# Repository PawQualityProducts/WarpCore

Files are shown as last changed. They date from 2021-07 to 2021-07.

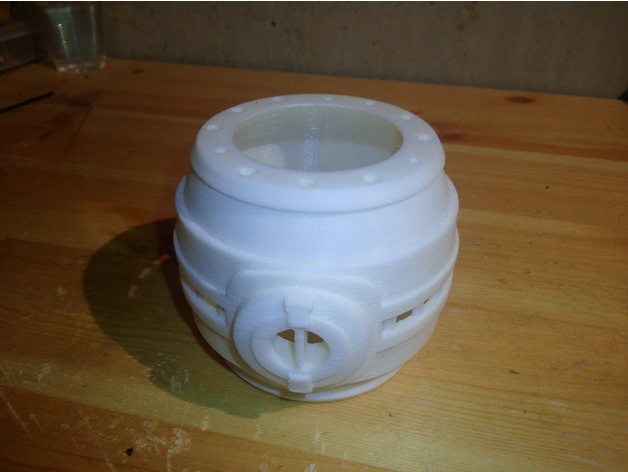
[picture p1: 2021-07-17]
images/a623d3ce466ae3677e4435cb19036652_preview_featured.JPG

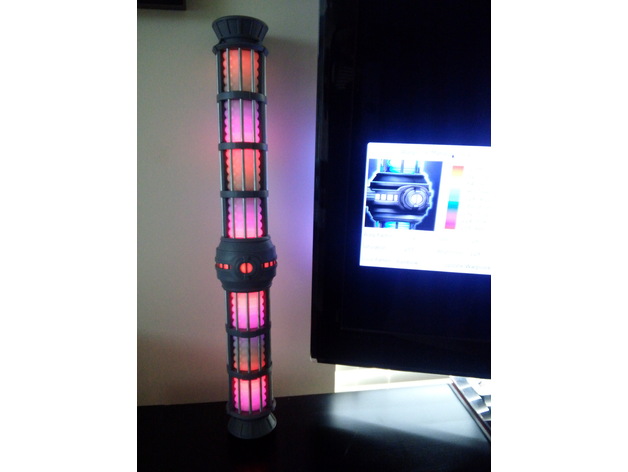
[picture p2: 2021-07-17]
images/a03e35211922563c592e2617a49f9ae8_preview_featured.JPG

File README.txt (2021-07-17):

                   .:                     :,                                          
,:::::::: ::`      :::                   :::                                          
,:::::::: ::`      :::                   :::                                          
.,,:::,,, ::`.:,   ... .. .:,     .:. ..`... ..`   ..   .:,    .. ::  .::,     .:,`   
   ,::    :::::::  ::, :::::::  `:::::::.,:: :::  ::: .::::::  ::::: ::::::  .::::::  
   ,::    :::::::: ::, :::::::: ::::::::.,:: :::  ::: :::,:::, ::::: ::::::, :::::::: 
   ,::    :::  ::: ::, :::  :::`::.  :::.,::  ::,`::`:::   ::: :::  `::,`   :::   ::: 
   ,::    ::.  ::: ::, ::`  :::.::    ::.,::  :::::: ::::::::: ::`   :::::: ::::::::: 
   ,::    ::.  ::: ::, ::`  :::.::    ::.,::  .::::: ::::::::: ::`    ::::::::::::::: 
   ,::    ::.  ::: ::, ::`  ::: ::: `:::.,::   ::::  :::`  ,,, ::`  .::  :::.::.  ,,, 
   ,::    ::.  ::: ::, ::`  ::: ::::::::.,::   ::::   :::::::` ::`   ::::::: :::::::. 
   ,::    ::.  ::: ::, ::`  :::  :::::::`,::    ::.    :::::`  ::`   ::::::   :::::.  
                                ::,  ,::                               ``             
                                ::::::::                                              
                                 ::::::                                               
                                  `,,`

https://www.thingiverse.com/thing:2008591
1701-D Warp Core (HI-RESOLUTION) by Novel_Mutations is licensed under the Creative Commons - Attribution - Non-Commercial license.
http://creativecommons.org/licenses/by-nc/3.0/

# Summary

I can't believe I hadn't seen ThePlanetMike's Warp Core Lamp or any of the others that followed before this week. I immediately downloaded it to start printing but I didn't feel it was up to star feet standards. I quickly brought it in to utopia planitia for a refit and this is what we ended up with.

It is 73% of the originals size but has the same power output. The resolution has been increased by a factor of at least three times and to the point that the facets are no longer visible. All parts now fit on a 100mm x 100mm bed.

In addition to increasing the resolution I have done the following:

The thin round posts are no longer printed. They are now replaced with 5mm diameter steel bars (metal braces I had lying around from the back of Ikea shelving units (now called HEJNE)). You could also use stainless steel automotive brake line tubing.

The ribbed "Vertical Tension Members" are now printed on their sides for a better finish and easier printing. They have a hole down the center for a piece of metal coat hanger wire as a support and to keep them all in line.

The "Magnetic Constrictor Lens" has been remodelled to be a solid which you only print the one perimeter, no infill and no top or bottom layers.

The lens inside the "Warp Reaction Chamber" is now one solid piece that you only print one perimeter, no infill and no top or bottom layers.

The "Phase Adjustment Coils" have been remodelled entirely without the round posts or the vertical tension members.

The "Reactant Injectors" have been entirely remodelled to have no intersecting faces.

The "Warp Reaction Chamber" has had some remodelling on the interior to use less plastic.

The Lamp base has been remodelled to be high resolution. I has a wire hole at the back for the power cord.

The only part that requires support is the "Warp Reaction Chamber".

The entire thing prints very quickly especially the single wall lens's.

UPDATE: May 17, 2018
Android program to control warpcore submitted by user Catmandu13 and is available on the google play store for free at https://play.google.com/store/apps/details?id=appinventor.ai_cterry42.WarpController2

UPDATE: Jan 2, 2017 : Added "Lamp Base.stl" to allow it to be used as a table lamp like the original one was intended. I also updated the Blend file with the new base.

UPDATE: Feb 6, 2017: Created http://www.thingiverse.com/thing:2090708 which is the light diffuser I used inside the model.

https://theledroom.wordpress.com/2017/02/13/ncc-1701-d-warp-core/

# Print Settings

Printer: Tantillus
Rafts: No
Supports: Yes
Resolution: 0.15

Notes: 
Print the Warp Reaction Chamber using support is recommended.

The Lens's should be printed using a single perimeter, zero infill and no top or bottom layers. Spiral mode if its an option.

# Post-Printing

Minimum printed parts:
1 - Reaction Chamber
1 - Reaction Chamber Lens
2 - Magnetic Constrictor Lens's
6 - Vertical Tension Members
2 - Reactant Injectors (or 1 - Reactant Injector and 1 - Lamp Base)
0 - Phase Adjustment Coils

For each additional section added you will need the following:
1 - Phase Adjustment Coil
1 - Magnetic Constrictor Lens
3 - Vertical Tension Members

# How I Designed This

To increase the resolution of the original parts I imported them into Blender and marked the sharp edges and then set the multi-resolution modifier to work. They are not applied in the Blend file so you can go in and adjust the resolution to your liking.

The parts that I completely remodelled are also done the same way but start off at a higher resolution. 

# Videos

<iframe src="//player.vimeo.com/video/202879164" frameborder="0" webkitallowfullscreen mozallowfullscreen allowfullscreen></iframe>
Running at Warp factor 2

<iframe src="//player.vimeo.com/video/202879163" frameborder="0" webkitallowfullscreen mozallowfullscreen allowfullscreen></iframe>
Running in rainbow mode

<iframe src="//player.vimeo.com/video/202879160" frameborder="0" webkitallowfullscreen mozallowfullscreen allowfullscreen></iframe>
Part of a Warp Core breach cycle

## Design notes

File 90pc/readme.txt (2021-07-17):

Components printed at 90% normal size allows for 4 restrictor lenses to be printed top and bottom

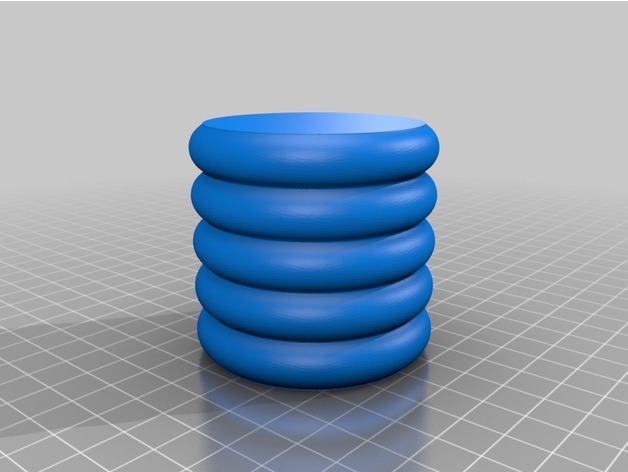
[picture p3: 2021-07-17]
images/d6bcbce92533f9e681ca99b0f44db99e_preview_featured.jpg

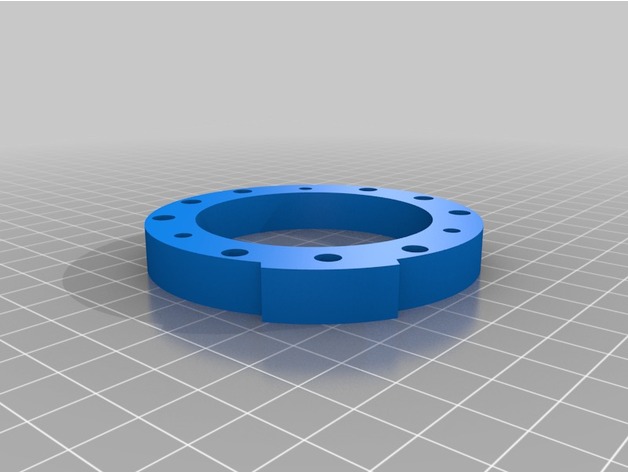
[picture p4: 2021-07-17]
images/adf16bbb0086b629d89b5c633a125ff6_preview_featured.jpg

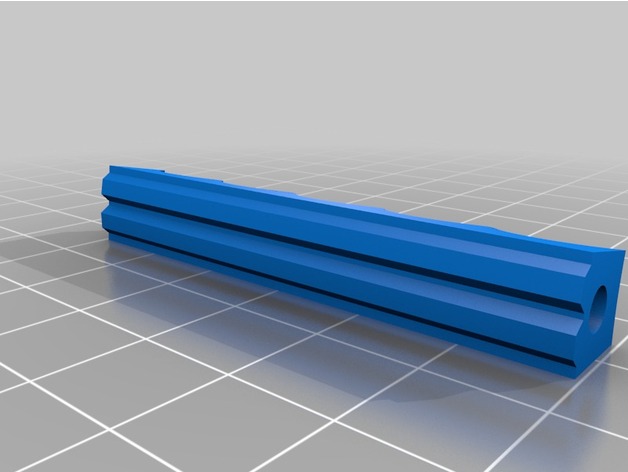
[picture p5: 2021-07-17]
images/73b58e25b4730450576f030052adf6e0_preview_featured.jpg

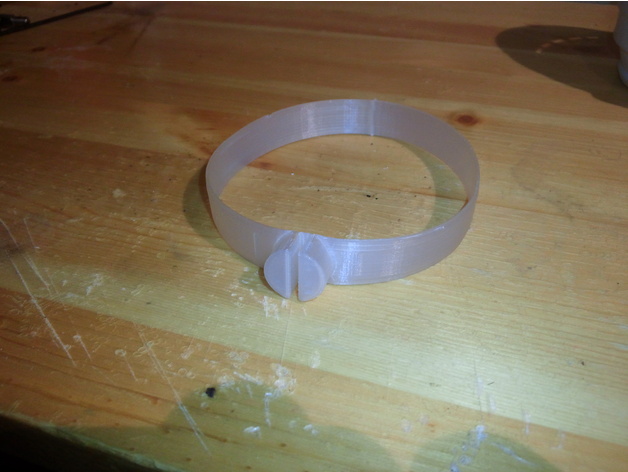
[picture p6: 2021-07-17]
images/f1cb4d1bf836be61b849b8668d147068_preview_featured.JPG

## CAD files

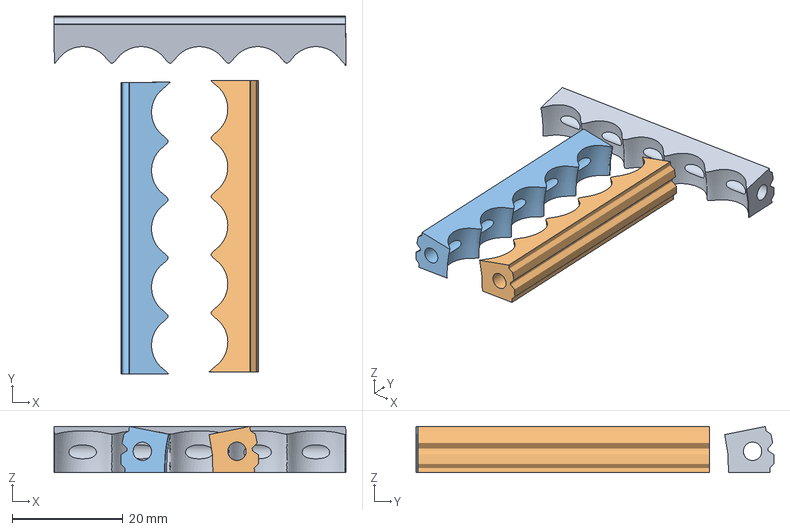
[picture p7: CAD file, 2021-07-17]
90pc/Cura/Vertical_Tension_Member_90pc.3mf
52.6 x 64.6 x 8.33 mm
Vertical_Tension_Member.stl
Vertical_Tension_Member.stl(1)
Vertical_Tension_Member.stl(2)

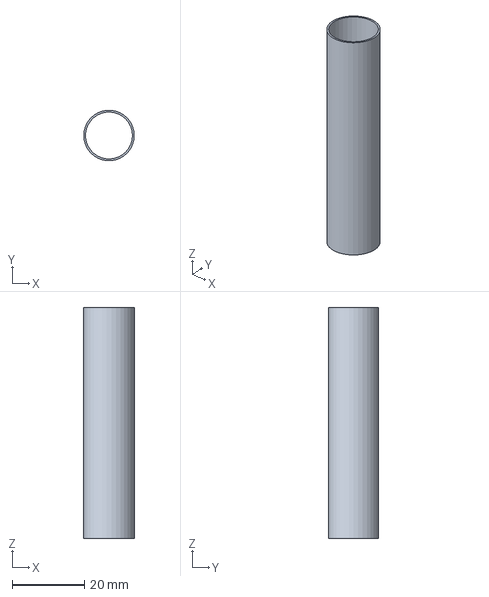
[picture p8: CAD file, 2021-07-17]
Cura/CE5P_diffuser_reactor.3mf
14.0 x 13.9 x 64.0 mm

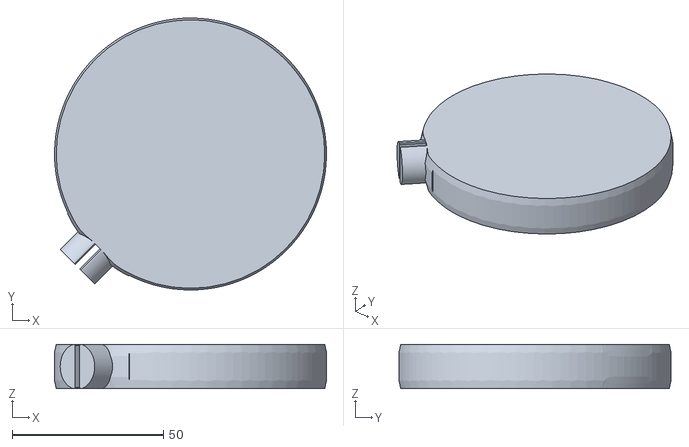
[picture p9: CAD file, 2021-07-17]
files/Warp_Reaction_Chamber_Lens.stl
89.8 x 89.8 x 14.6

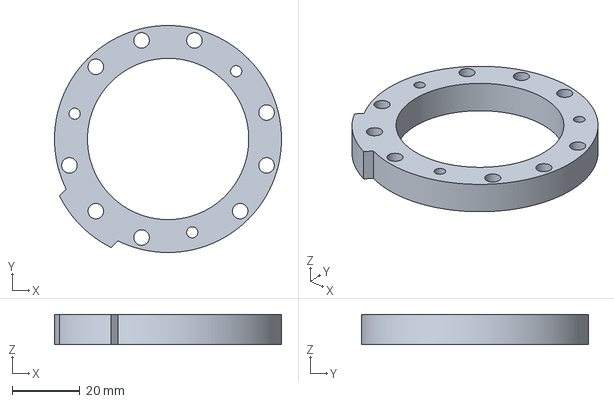
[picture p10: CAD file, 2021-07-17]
90pc/Cura/CE5P_Phase_Adjustment_Coil_90pc.3mf
67.3 x 67.3 x 9.00 mm

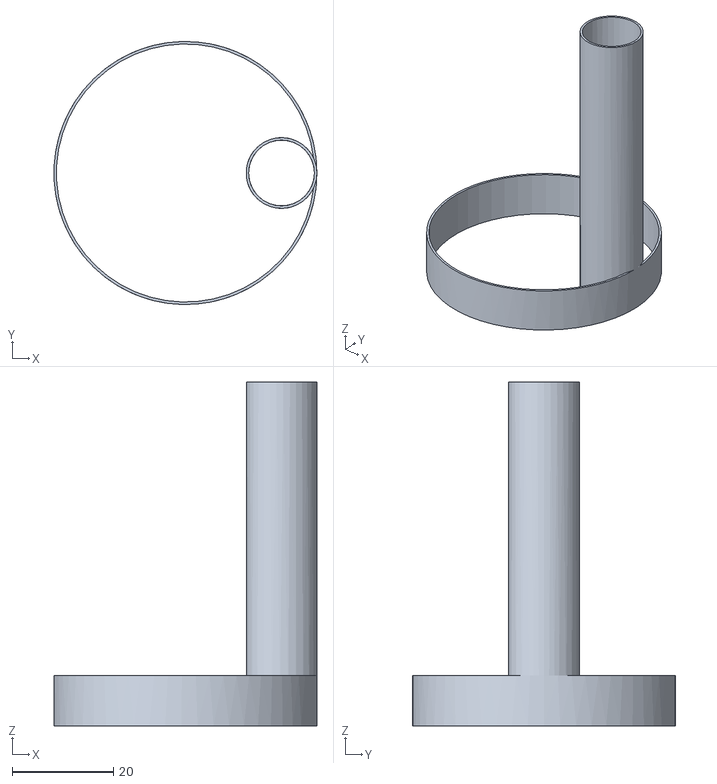
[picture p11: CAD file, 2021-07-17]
files/diffuser.stl
52.0 x 52.0 x 68.0

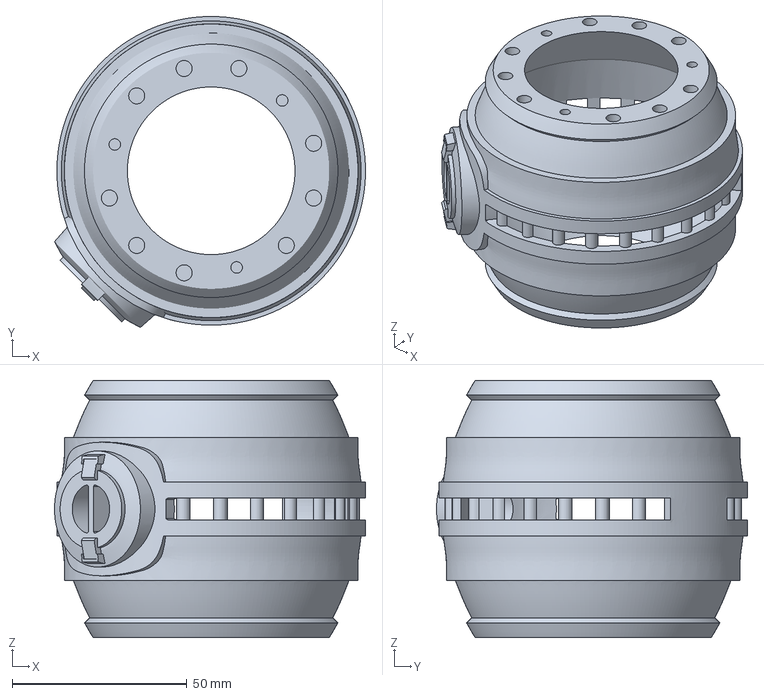
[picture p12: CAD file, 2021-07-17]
90pc/Cura/CE5P_Warp_Reaction_Chamber_90pc.3mf
88.9 x 88.9 x 73.6 mm

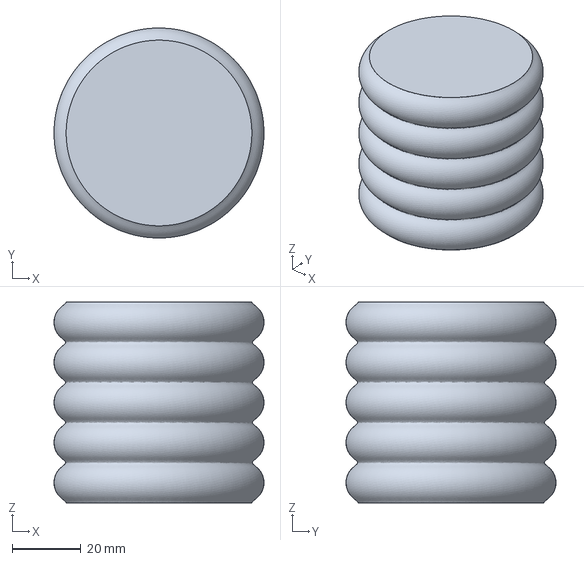
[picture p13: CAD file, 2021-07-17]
Cura/CE5P_Magnetic_Constrictor_Lens.3mf
61.2 x 61.2 x 58.4 mm

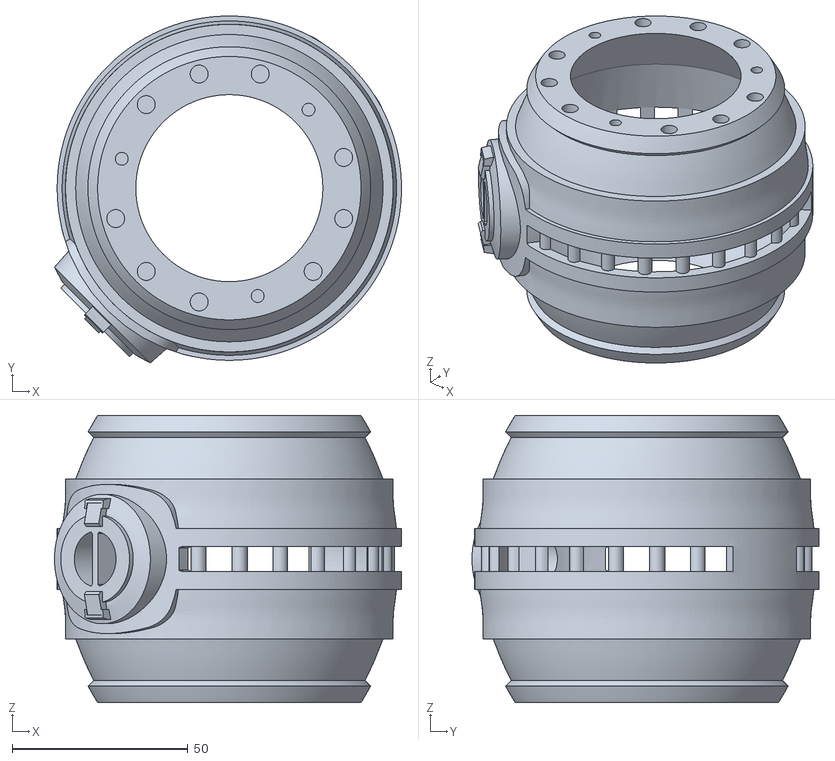
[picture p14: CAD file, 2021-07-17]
files/Warp_Reaction_Chamber.stl
98.8 x 98.8 x 81.8

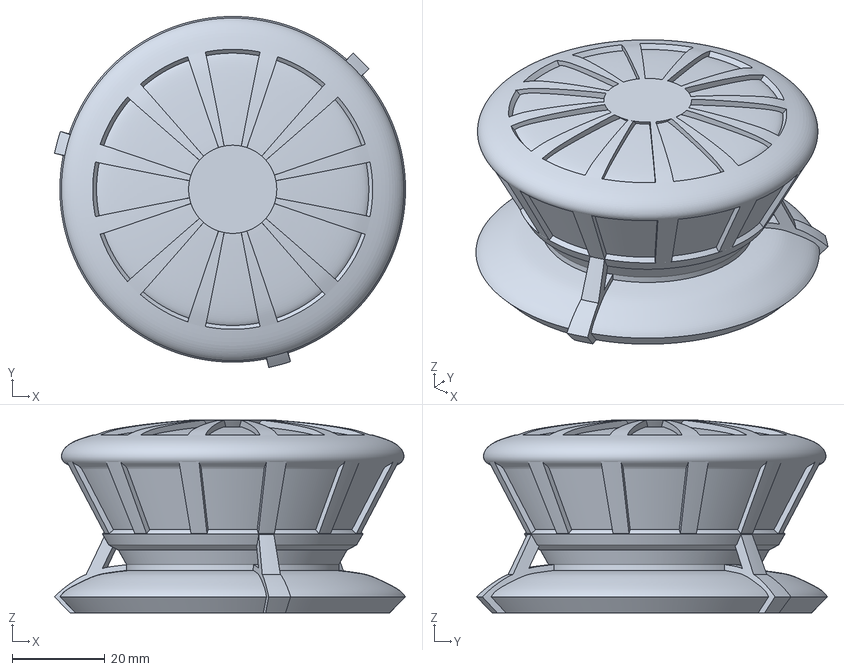
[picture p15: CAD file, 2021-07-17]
90pc/Cura/CE5P_Reactant_Injector_90pc.3mf
75.6 x 75.6 x 41.5 mm

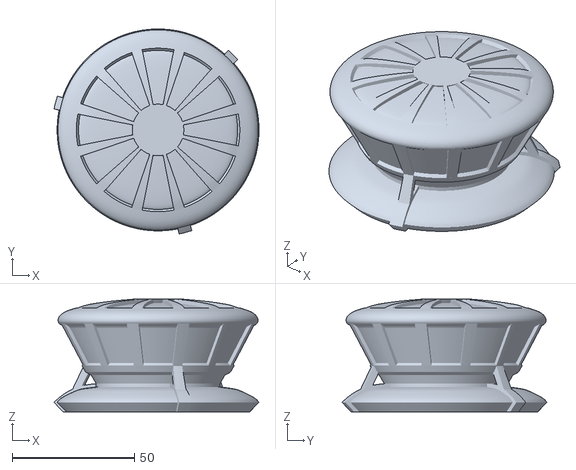
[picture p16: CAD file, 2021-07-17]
files/Reactant_Injector.stl
84.0 x 84.0 x 46.1

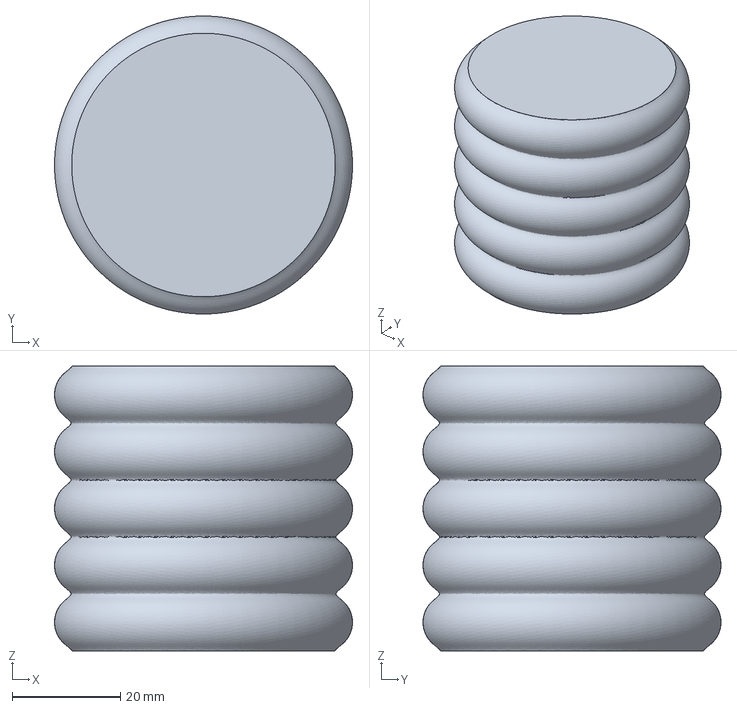
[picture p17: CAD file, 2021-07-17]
90pc/Cura/CE5P_Magnetic_Constrictor_Lens_90pc.3mf
55.1 x 55.1 x 52.6 mm

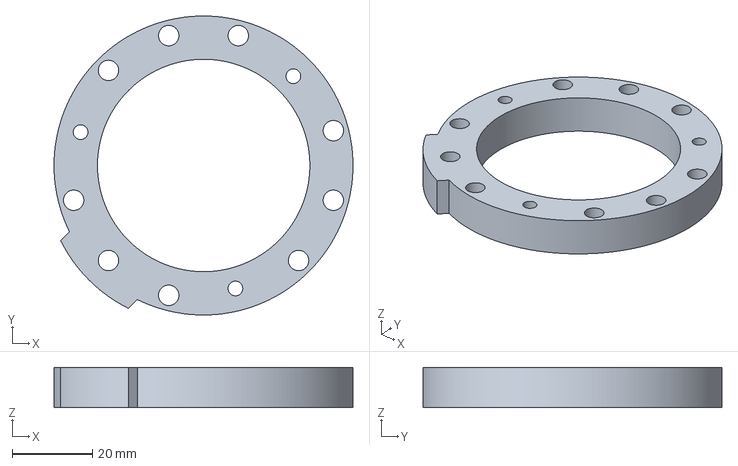
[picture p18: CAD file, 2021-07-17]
Cura/CE5P_Phase_Adjustment_Coil.3mf
74.7 x 74.7 x 10.0 mm

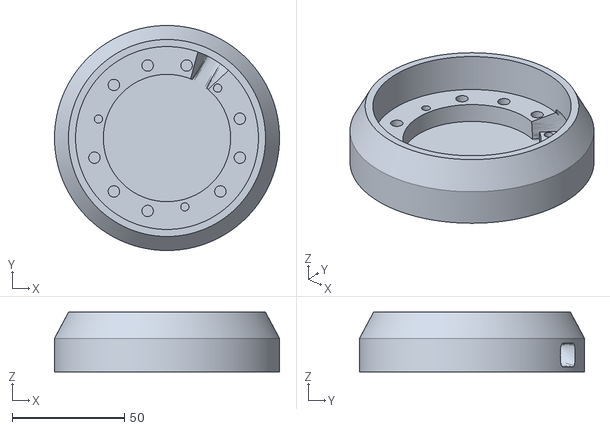
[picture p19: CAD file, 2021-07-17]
files/Lamp_Base.stl
100.4 x 100.4 x 26.7

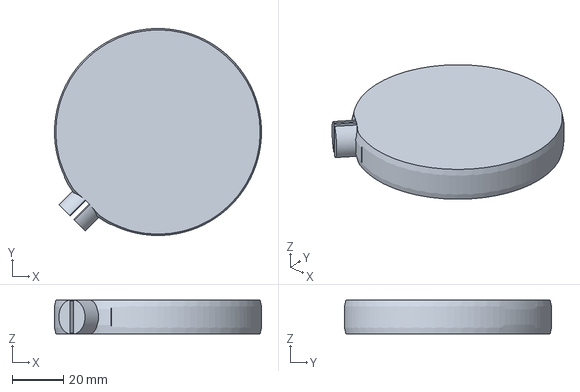
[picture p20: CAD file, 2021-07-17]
90pc/Cura/CE5P_Warp_Reaction_Chamber_Lens_90pc.3mf
80.8 x 80.8 x 13.1 mm

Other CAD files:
Cura/CE5P_Warp_Reaction_Chamber_Lens.3mf
Cura/CE5P_diffuser.3mf
Cura/CE5P_Reactant_Injector.3mf
files/Phase_Adjustment_Coil.stl
Cura/CE5P_Lamp_Base.3mf
Cura/CE5P_Warp_Reaction_Chamber.3mf
Cura/CE5P_diffuser_support.3mf
files/Magnetic_Constrictor_Lens.stl
files/Vertical_Tension_Member.stl
files/diffuser_reactor.stl
files/diffuser_support.stl

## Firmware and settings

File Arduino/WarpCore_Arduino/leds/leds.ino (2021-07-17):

#include <FastLED.h>
#define LED_PIN     6
#define NUM_LEDS    72
CRGB leds[NUM_LEDS];

void setup() {
  FastLED.addLeds<WS2812, LED_PIN, GRB>(leds, NUM_LEDS);
}

void loop() {
  for (int i = 0; i <= 36; i++) {
    leds[i] = CRGB ( 0, 0, 255);
    //FastLED.show();
    leds[72-i] = CRGB ( 0, 0, 255);
    FastLED.show();
    
    if(i>0)
    {
      leds[i-1] = CRGB ( 0, 0, 0);
    //FastLED.show();
      leds[72-i] = CRGB ( 0, 0, 0);
    FastLED.show();
    }      
  
    //FastLED.show();
    delay(15);
  }
/*
  for (int i = 7; i >= 0; i--) {
    leds[i] = CRGB ( 255, 0, 0);
    FastLED.show();
    delay(40);
  }
   for (int i = 0; i <= 7; i++) {
    leds[i] = CRGB ( 0, 255, 0);
    FastLED.show();
    delay(40);
  }
*/
}

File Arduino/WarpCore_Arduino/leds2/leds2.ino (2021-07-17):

#include <FastLED.h>
#define LED_PIN     6
#define NUM_LEDS    72
CRGB leds[NUM_LEDS];

void setup() {
  FastLED.addLeds<WS2812, LED_PIN, GRB>(leds, NUM_LEDS);
}

void loop() {
  for (int i = 0; i <= 41; i++) {
    leds[72-i] = CRGB ( 0, 0, 255);
    if(i>10)
      leds[i-11] = CRGB ( 255, 0, 0);
      
    FastLED.show();
    
    if(i>0)
    {
      leds[72-i] = CRGB ( 0, 0, 0);
      if(i>11)
        leds[i-12] = CRGB ( 0, 0, 0);
      FastLED.show();
    }      
    delay(15);
  }
  leds[30] = CRGB ( 255, 255, 255);
  FastLED.show();
  delay(15);
  leds[30] = CRGB ( 0, 0, 0);
  FastLED.show();

}
